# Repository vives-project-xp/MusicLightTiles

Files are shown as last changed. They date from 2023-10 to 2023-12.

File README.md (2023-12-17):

# MusicLightTiles

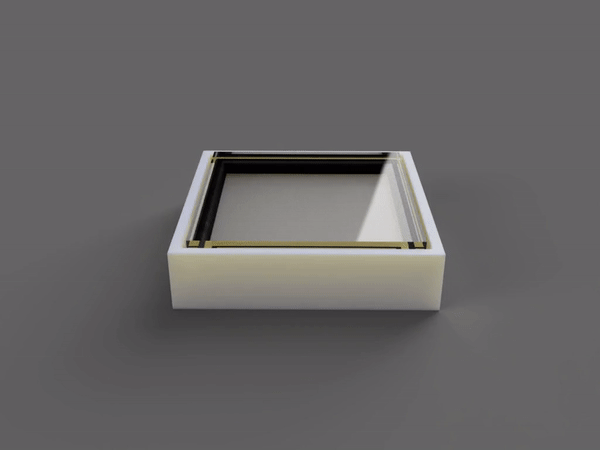
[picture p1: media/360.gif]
360° view


## About

Welcome to the MusicLightTiles project!  
This project was created as part of the Project Experience course at [VIVES University of Applied Sciences](https://www.vives.be/en).  
The goal of this project was to create a Proof of Concept interactive floor tile that can play music and light up when someone stands on it.
The tile also needed to work with [Project Master](https://github.com/vives-project-xp/ProjectMaster).  

## The team

- [Rob Cocquyt](https://github.com/Robbedoes24)
- [Ruben Belligh](https://github.com/RubenBelligh)
- [Luca De Clerck](https://github.com/LucaClrk)
- [Alberiek Depreytere](https://github.com/AlberiekDepreytere)

## Features

- Small form factor
- Can work standalone or as a set
- Hardcoded and wireless modes
- Add your own music
- Individualy addressable RGB leds
- Tested for 85kg of weight
- Can detect people starting from 5kg
- Works with [Project Master](https://github.com/vives-project-xp/ProjectMaster)

## How it works

Each tile has an ESP32 microcontroller that controls the lights and music and detects when someone stands on the tile.  
The tile reacts differently depending on the mode it is in, more info about this in the [Modes](#modes) section.  

### Person detection

To detect when someone stands on the tile, the ESP32 uses a simple circuit with 2 conductive strips.  
When someone stands on the tile, the conductive strips touch each other and close the circuit.  
To make sure the circuit is normally open, the tile uses seal strip to keep the plate (where people stand on) and the base (where the circuit is) separated.  
This way, the circuit is only closed when someone stands on the tile, because the seal strip is compressed.  
When the person later leaves the tile, the seal strip will decompress and push the plate back up, opening the circuit again.  

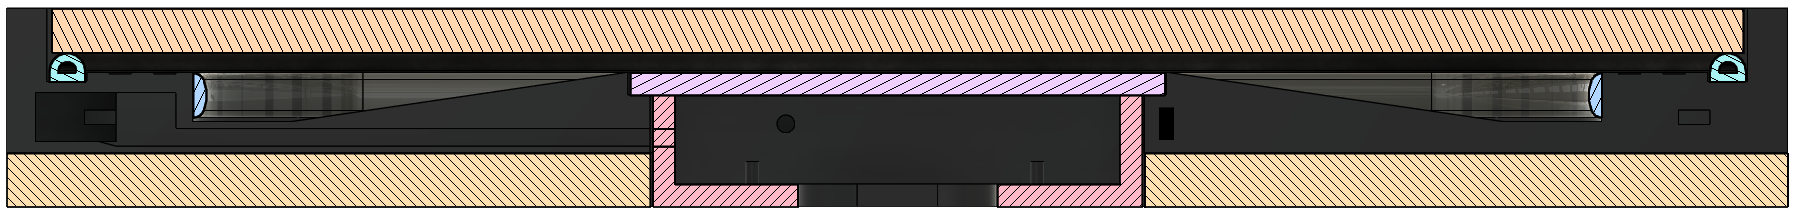
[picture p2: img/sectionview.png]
Section View


### Audio

For the audio, we use a DFPlayer Mini.
This is a small mp3 player that can be controlled with a serial connection.  
The ESP32 sends commands to the DFPlayer Mini to play, pause, stop, change volume, etc.  
The player has a micro SD card slot where you can put your own music.  
This player also has a built-in amplifier, so you can connect a speaker directly to it (3W speaker recommended).  

### Lights

For the lights, we use a WS2814 LED strip.  
This is a 24v LED strip with individually addressable RGB led sections.  
Each section has 6 leds and is about 10cm long.  

## Modes

The tiles can work in 2 modes:

- Hardcoded mode (Demo mode)
- Wireless mode (MQTT mode)

### Demo mode

In this mode, every tile will work on its own.  
When someone stands on a tile, the lights will turn on and music will start playing.  
When the person leaves the tile, the lights will turn red  and music will stop.  

### MQTT mode

In this mode, the tiles basically function as a sensor and actuator.  
When the state of a tile changes (like when someone stands on it), it will send a message to the MQTT broker.  
When a tile receives a command from the MQTT broker, it will execute the command and change its state accordingly.  

With the help of the server, you can control multiple tiles with the same command.  
This makes it possible to create a set of tiles that work together and can be controlled from a single point.  

## Project state

This project is currently in a working state.  
The tiles can be used in both modes and can be controlled with the [Project Master](https://github.com/vives-project-xp/ProjectMaster).  
There is an api available to control the tiles with websocket messages.
We started on a web interface to control the tiles, but this is not finished yet.

## Documentation

If you want to build your own tile(s) or build further on this project, you can find all aditional information in the [Wiki](https://github.com/vives-project-xp/MusicLightTiles/wiki).    

## Future improvements

- Finish the web interface.
- Replace the led strip with a 5v one, so the leds can be controlled individually.
- Replace the DFPlayer Mini with custom circuitry, so there won't be any delay when playing music.
- Add effects to the control server.
- Make the tiles cheaper to produce (so they can be used in schools, etc.).

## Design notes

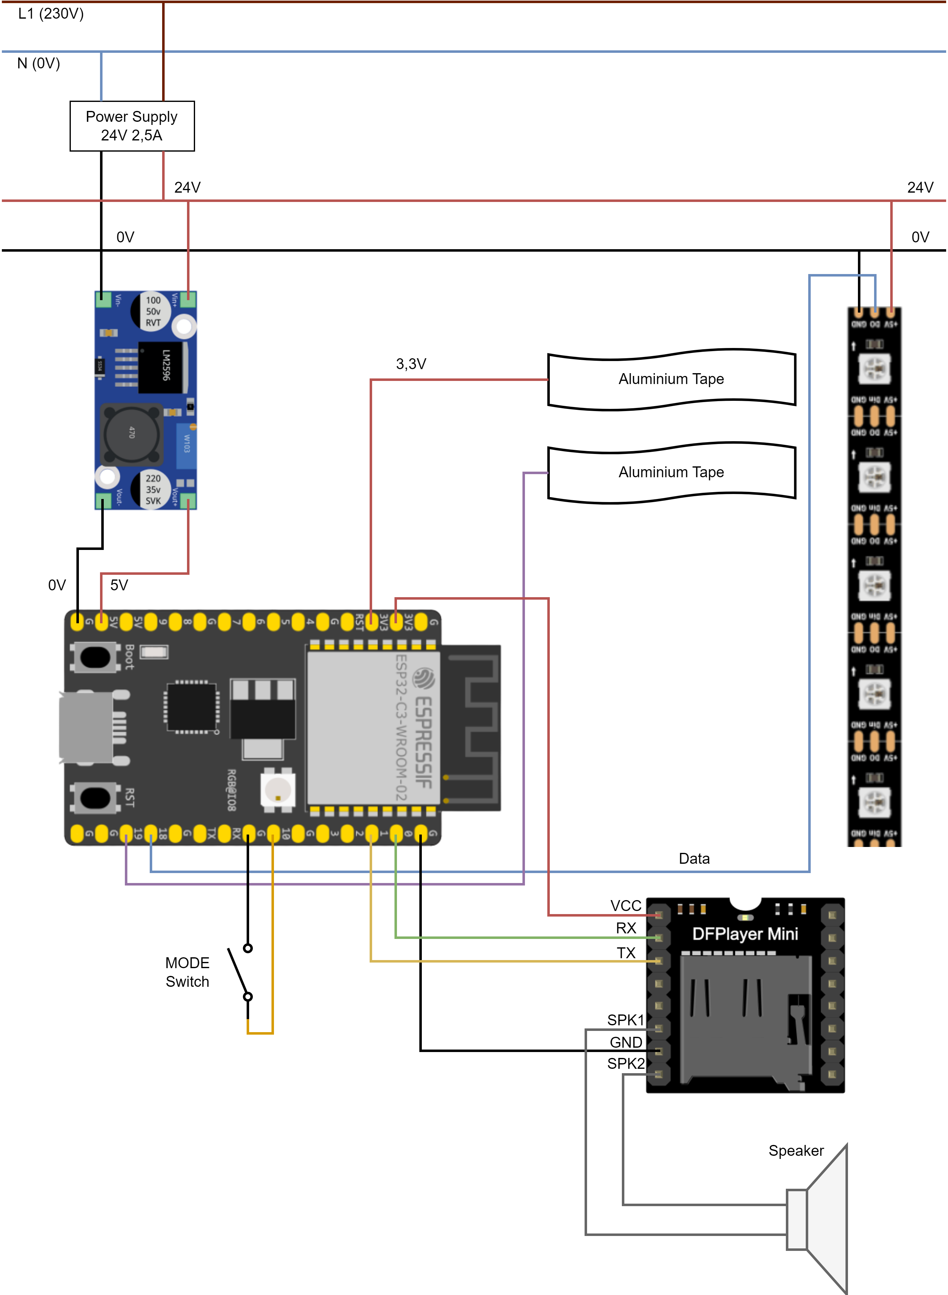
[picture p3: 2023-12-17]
img/electrical_diagram_v1.png

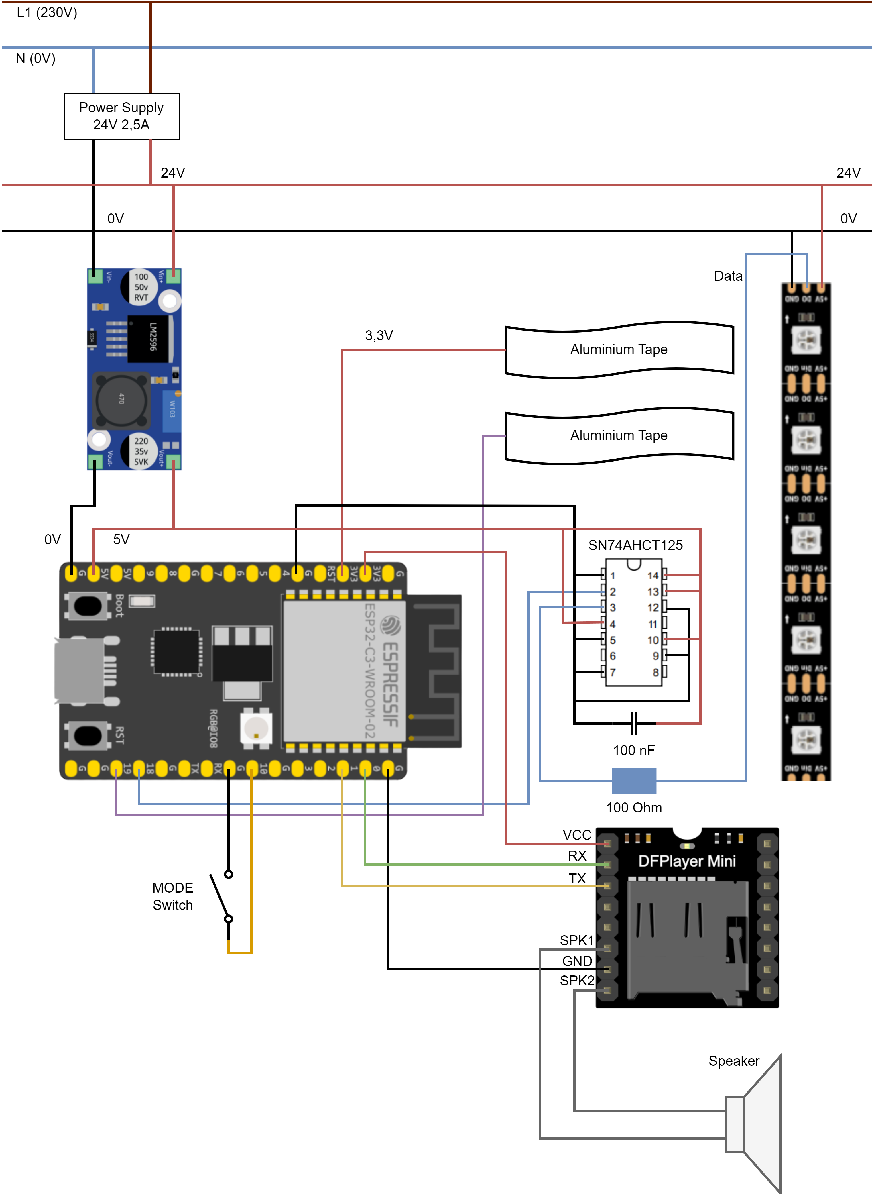
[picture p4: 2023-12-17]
img/electrical_diagram_v2.png

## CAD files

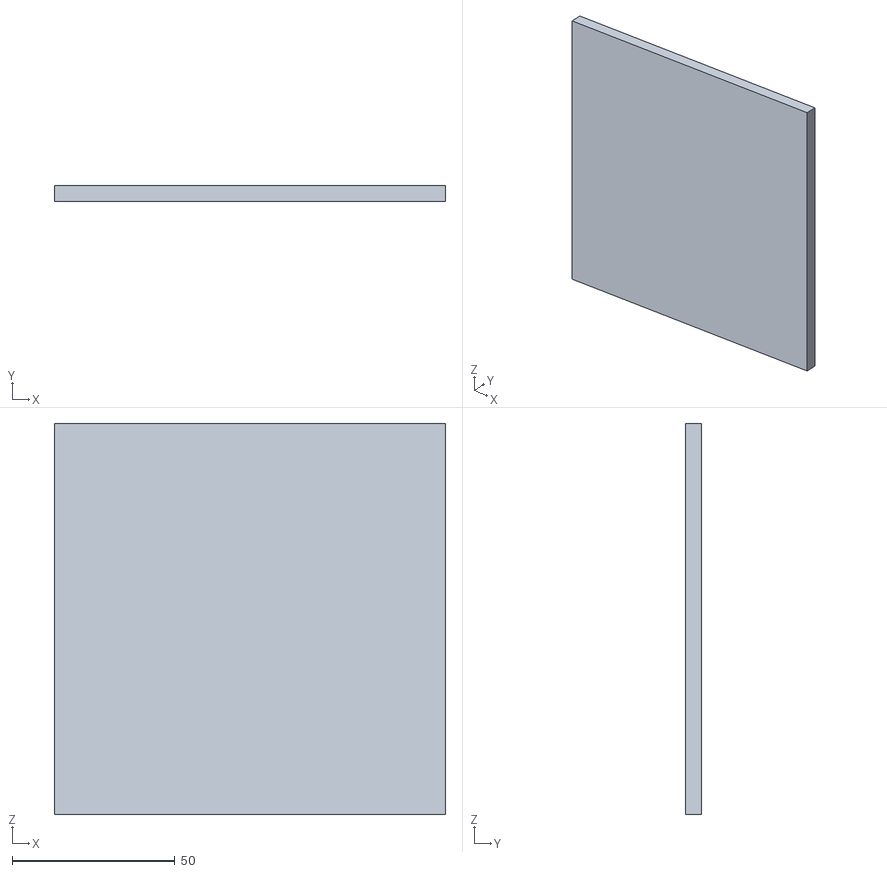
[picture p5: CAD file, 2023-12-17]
hardware/v2/stl/Electronics-box-lid.stl
120.0 x 5.00 x 120.0

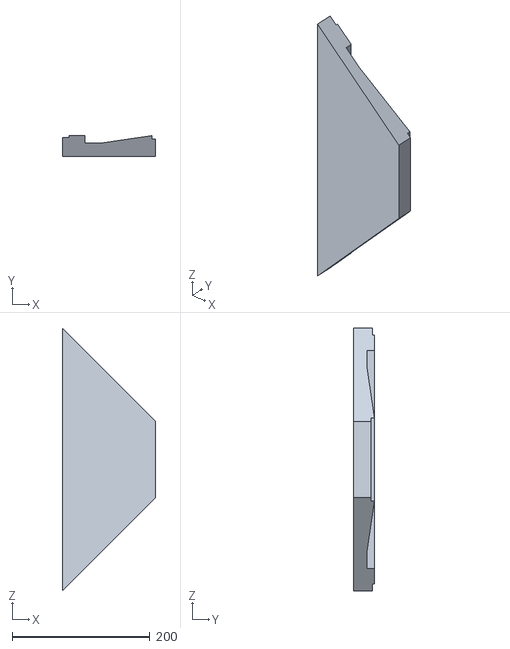
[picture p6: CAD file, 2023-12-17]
hardware/v2/stl/Base-type1.stl
135.5 x 30.0 x 382.0

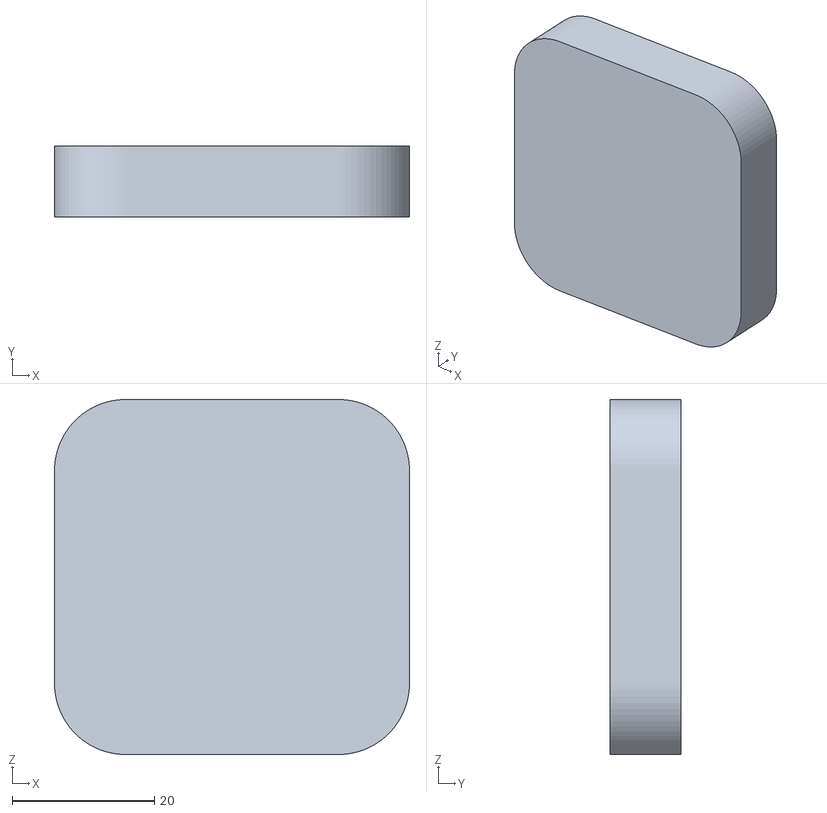
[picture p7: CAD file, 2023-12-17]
hardware/v2/stl/Feet.stl
50.0 x 10.0 x 50.0

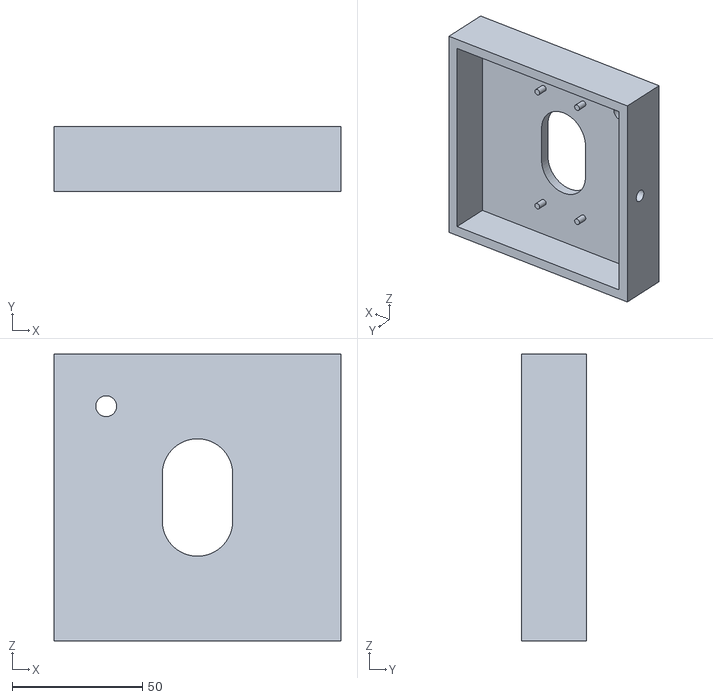
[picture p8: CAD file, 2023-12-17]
hardware/v2/stl/Electronics-box.stl
110.0 x 25.0 x 110.0

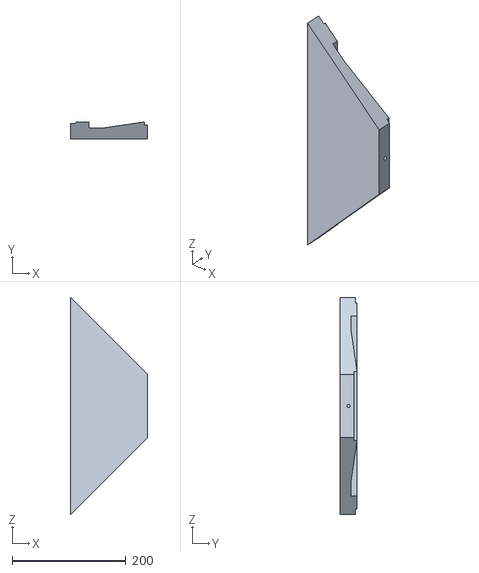
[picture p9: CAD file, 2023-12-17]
hardware/v2/stl/Base-type2.stl
135.5 x 30.0 x 382.0

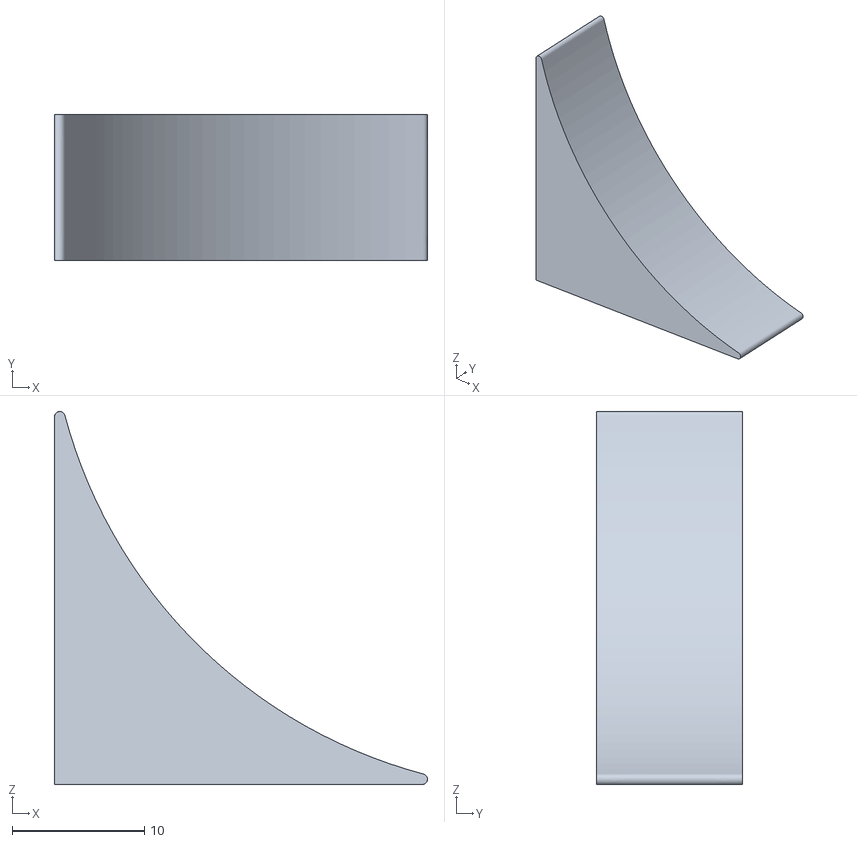
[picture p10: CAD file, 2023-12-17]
hardware/v2/stl/Corner.stl
28.2 x 11.0 x 28.2

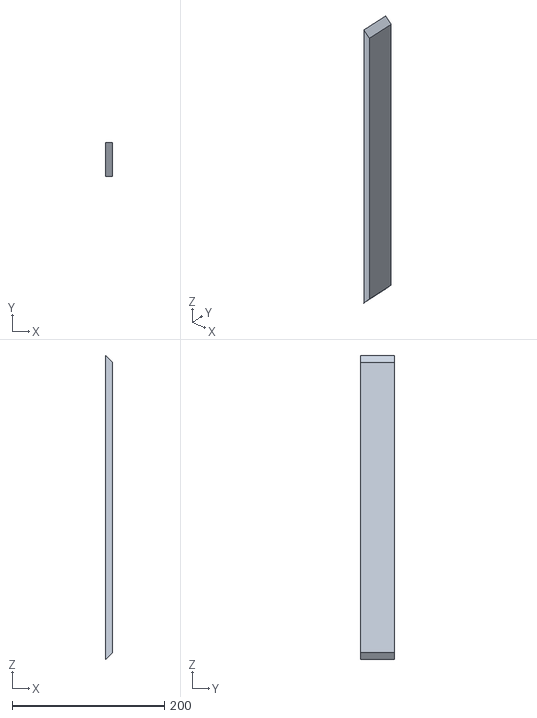
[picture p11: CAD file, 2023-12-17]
hardware/v2/stl/Side.stl
9.00 x 45.0 x 400.0

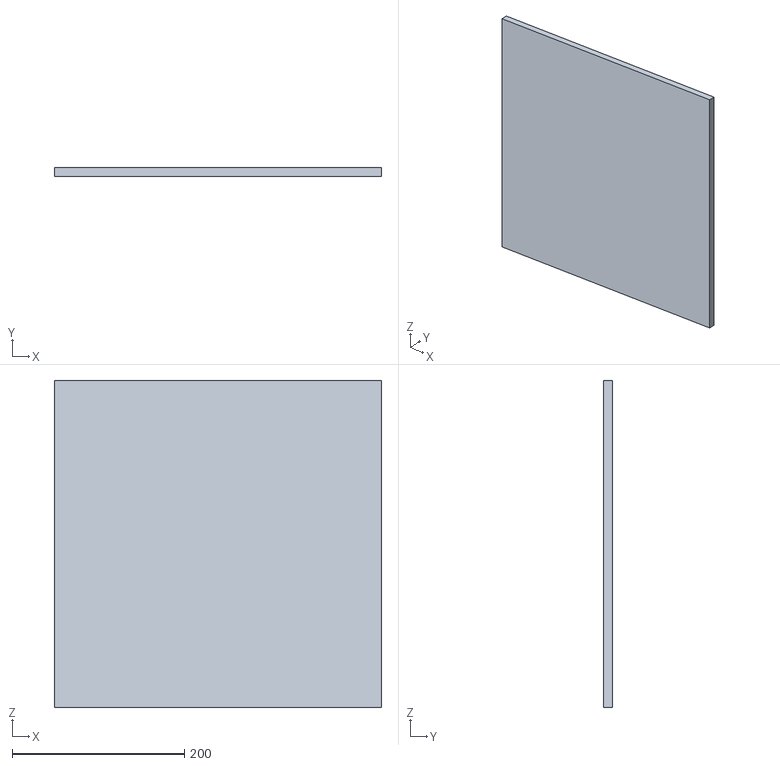
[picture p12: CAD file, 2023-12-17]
hardware/v2/stl/Plate.stl
380.0 x 10.0 x 380.0

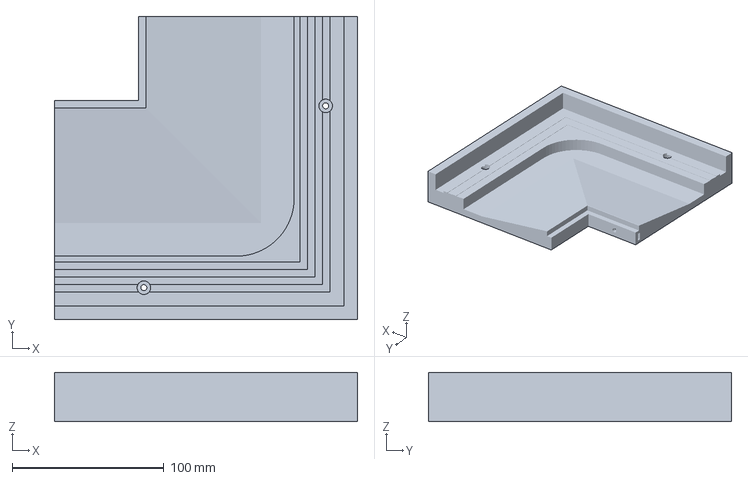
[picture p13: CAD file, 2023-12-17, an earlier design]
hardware/v1.5/cura/BaseCorner_Type1.3mf
200.0 x 200.0 x 32.5 mm

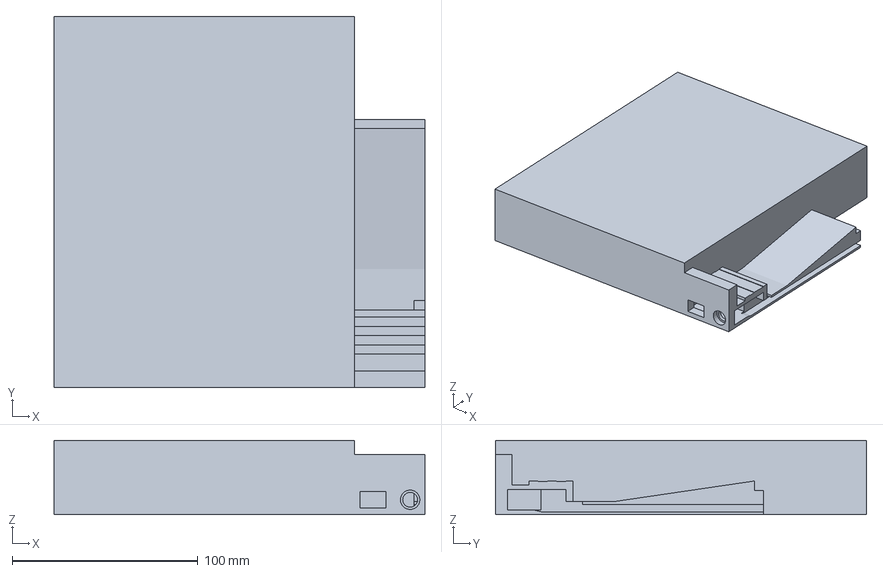
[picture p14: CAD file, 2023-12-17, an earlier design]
hardware/v1/cura/BaseCorner_Type2.3mf
200.0 x 200.0 x 40.0 mm

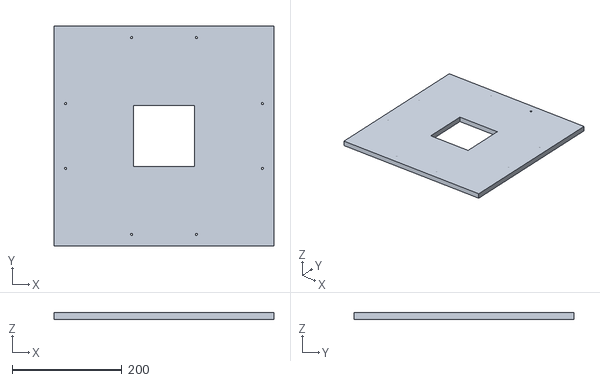
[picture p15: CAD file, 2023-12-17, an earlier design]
hardware/v1/stl/BasePlate.stl
400.0 x 400.0 x 12.0

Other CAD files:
hardware/v1.5/stl/BaseCorner_Type2.stl
hardware/v1/stl/InsertCover.stl
hardware/v1.5/stl/BaseCorner_Type1.stl
hardware/v1/stl/BaseCorner_Type2.stl
hardware/v1.5/stl/Insert.stl
hardware/v1.5/3d/Speaker.f3d
hardware/v1.5/3d/Tile.f3z
hardware/v1.5/stl/InsertCover.stl
hardware/v1.5/stl/Plate.stl
hardware/v1/3d/Speaker.f3d
hardware/v1/3d/Tile.f3z
hardware/v1/stl/BaseCorner_Type1.stl
hardware/v1/stl/Insert.stl
hardware/v1/stl/Plate.stl
hardware/v2/3d/Speaker.f3d
hardware/v2/3d/TileV2.f3z

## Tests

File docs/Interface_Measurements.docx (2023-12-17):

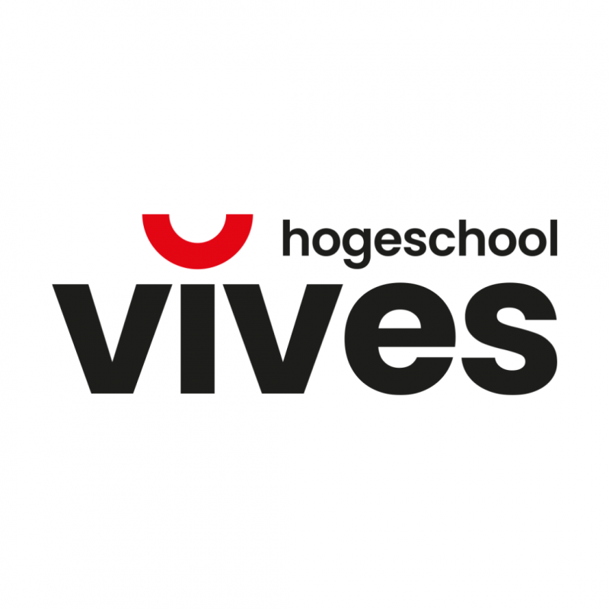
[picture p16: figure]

Opleiding: | Bachelor in de elektronica-ICT | Academiejaar: | 2023 – 2024
Klas: | / | Naam: | Alberiek Depreytere
Groepsleden: | Ruben Belligh Rob Cocquyt Luca De Clerck | Datum uitvoering: | Week van 11 December

o | Verslag - opdracht
o | Voorbereiding
Opleidingsonderdeel: | Project Experience
Titel opdracht: | Elektrische schema’s

# Inleiding

In dit verslag zijn alle versies van onze tegel terug te vinden. De werking en ook onze definitieve uitwerking.

# 1. VERSIE 1

Dit is het eerste prototype

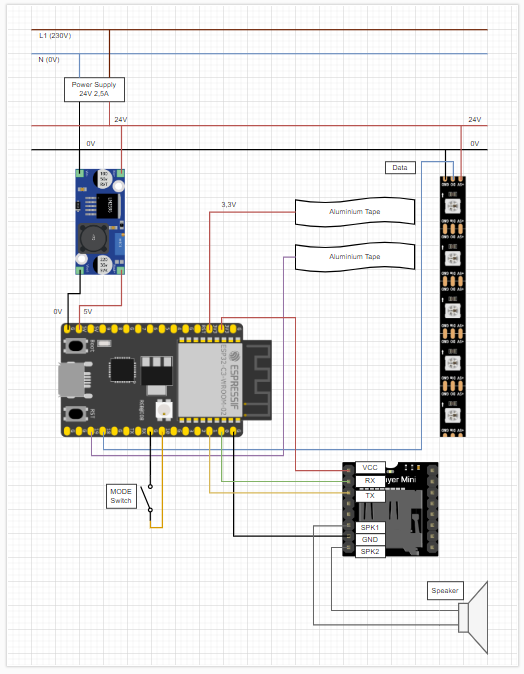
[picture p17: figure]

# 2. VERSIE 1.5

Dit is het tweede prototype.

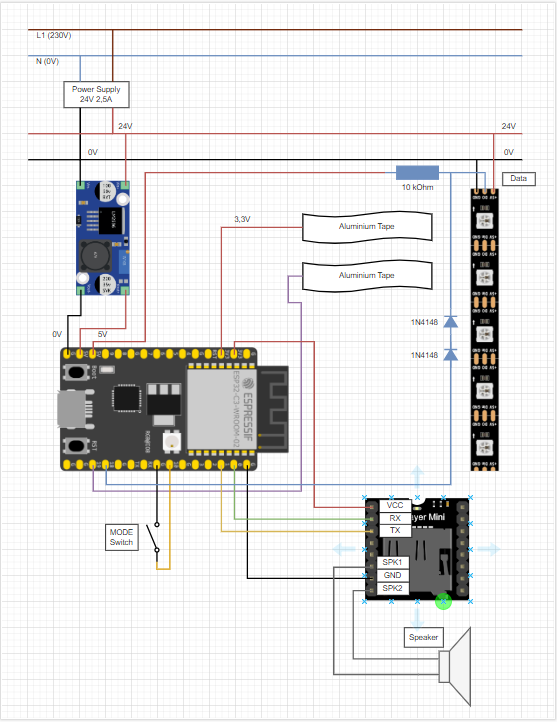
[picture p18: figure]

Componenten en werking.

We gebruiken een 24 Volt adapter voeding met barreljack (kortweg 24V voeding). In de schakeling wordt deze door de LM2596S DC-DC Step down Module (kortweg stepdown) verlaagd naar ±5V.

De ESP32-C3-DevKit-02 (kortweg ESP), waar onze code is op ingeladen, wordt gebruikt voor het aansturen van de Volledige schakeling.

Bij de MP3-TF-16P (kortweg MP3) in de schakeling zit er een 3W 8 Ohm speaker die wordt aangestuurd door de mp3 module (en die op zijn beurt door de ESP). Deze werkt via de RX en TX lijn samen met de esp. Voor seriële communicatie.

De WS2814 ledstrip (kortweg leds) wordt ook aangestuurd ook door de ESP.

Bij dit prototype helpt een 1n4148 diode ervoor dat de 5 Volt niet in aanraking komt met de 3V3 van onze ESP. Samen met een 10 kOhm weerstand.

We hebben ook een kleine 2pins modeswitch aangebracht voor wanneer onze ESP met het netwerk verbonden moet zijn of standalone kan werken. De Mp3 speler leest de data af van de SD kaart die met vooraf aangevulde liedjes werkt.

De aluminium plakband zorgt ervoor dat bij connectie (Wanneer er iemand op de tegel staat.) De Esp een signaal binnen zal krijgen en in werking zal kunnen treden.

Hieronder zijn de waarden in de schakeling genoteerd zoals te zien is wijken deze soms af van de theroretische waarden. In dit geval is het echter niet te veel om zorgen over te maken.

| Spanning
Leds | 24,263V
Leds full brightness | 24,212V | (Fel wit licht)
Detectie | 3,287V
DC/in | 24,258V | (Powersupply)
DC/out | 4,896V | (Uit de
GND en 5V ESP | 4,895V
3V3 | 3,295V | (ESP32-C3-DevKitC-02)
Switchon | 0,0025mV
Switchoff | 3,846V
VCC mp3 | 3,295V

Hieronder staan enkele voorbeelden van de seriële communicatie die plaatsvind tussen de MP3 speler en de ESP.

Bij onderstaande signalen zie je duidelijk dat we eerst een startbyte krijgen met daarna de data en de selectie van de registers (selecteren op de SD kaart welk liedje er afgespeeld moet worden, daarna komt er een duidelijk stop signaal) bij de scoop konden we dit niet naar Ruwe data vertalen (1- en 0-en).

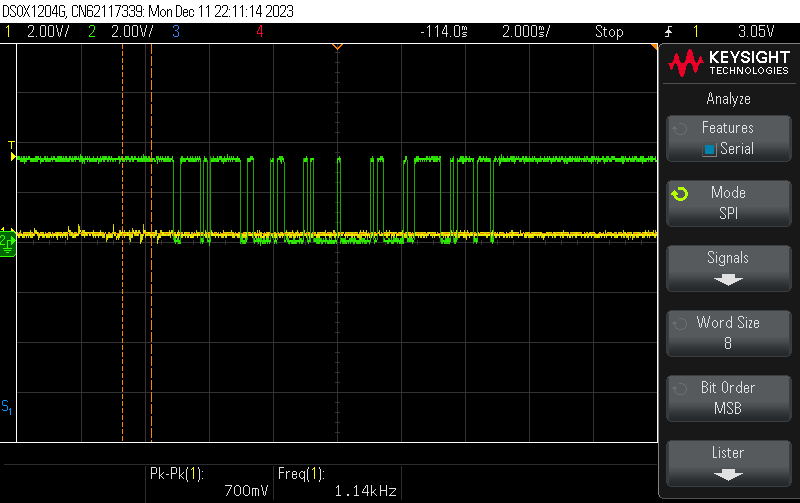
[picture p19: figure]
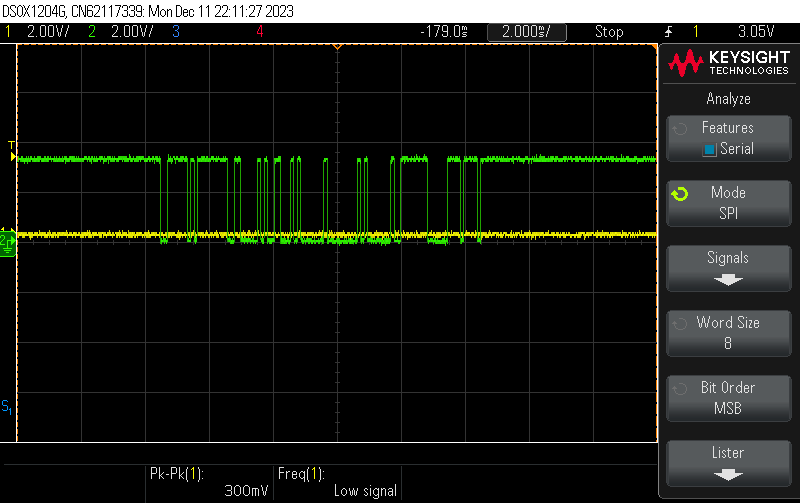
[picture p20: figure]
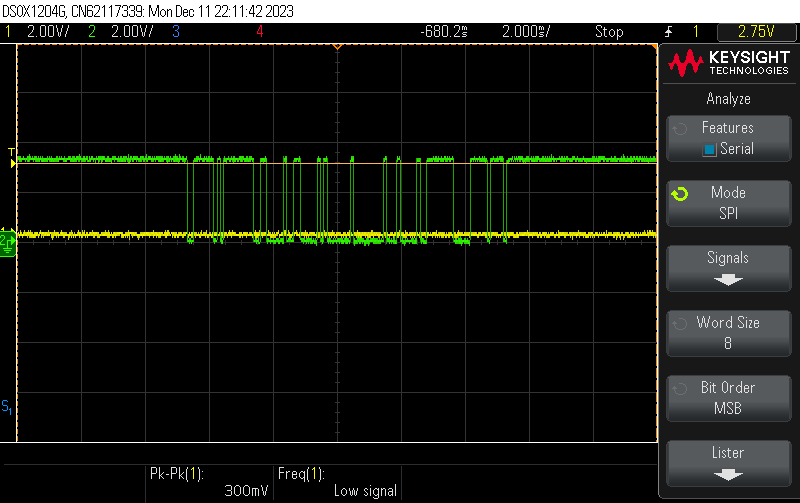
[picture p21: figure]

# 3. VERSIE 2

Dit is onze definitieve versie In tegenstelling tot het vorige prototype gebruiken we hier een levelshifter.

Ons datasignaal zal stabieler worden verhoogd (geschift naar een hoger lever).

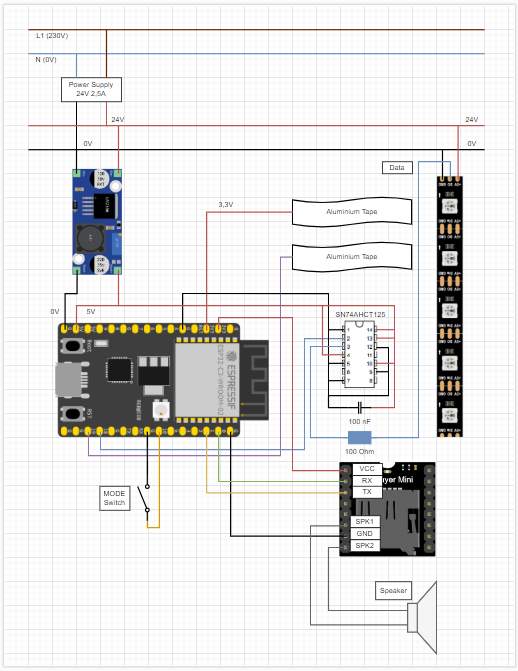
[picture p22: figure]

KATHOLIEKE HOGESCHOOL VIVES – STUDIEGEBIED IW&T – CAMPUS BRUGGE, KORTRIJK en OOSTENDE 1

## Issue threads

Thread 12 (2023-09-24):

Program detection section

Robbedoes24, 2023-09-24:
Create a program to detect the presence of something/someone using the controller and the detection methode.

Robbedoes24, 2023-10-08:
Added initial PlatformIO project to detect branch

RubenBelligh, 2023-10-09:
I've watched videos on how to program with arduino. The reason for this is that I have never programmed with Arduino.

RubenBelligh, 2023-10-09:
I programmed the detection. The button allows pin 16 to connect to the ground.

RubenBelligh, 2023-10-16:
I have made a flowchart of my program. In that chart you can see easily what it does.

Robbedoes24, 2023-10-19:
Merged feature detect into develop

Closed 2023-10-19.

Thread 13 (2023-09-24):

Program lighting section

Robbedoes24, 2023-09-24:
Create a program to adjust the lighting using the controller and the lighting solution.

Robbedoes24, 2023-10-08:
Added initial PlatformIO project to light branch

LucaClrk, 2023-10-09:
# First code for ledstrip
Today I finished the first code for the ledstrip. I used the Adafruit Neopixel library as it was the best for our ledstrip, the WS2814 RGBW. First I tested what this ledstrip could do. After testing we learned that this ledstrip is divided in segments of 6 leds. So this means we can't program each led individually but we can program each segment as we want. For 1 tile we needed 16 segments as this was around 1.6 meters. The length we needed for 1 tile. We know that the ledstrip will eventually be controlled by a signal sent by MQTT. I will receive an array that will control what segments light up and which color they will have. So for testing I made a 2D array "arrayPixel[16][4]. This basically says it contains 16 segments and 4 colors. It's an RGBW ledstrip so we have red, blue, green and a white led for additional brightness. Then I iterate over this array with a for loop. The for loop will go over all the segments and will determine the colors. I will make this clear with the following screenshots.

### The array
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
This is the array I used for my testing. In the next phase this array will be sent through MQTT.

### The for loop
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
Here you see the for loop iterating over the "NUMPIXELS". "NUMPIXELS" is equal to 16 and is declared above the setup. It says the amount of segments used. Next you can see all the colours [0, 1, 2, 3]. Later defined as red, white, green and blue. At last I say that the leds will work on a brightness of 50%.

LucaClrk, 2023-10-09:
# Backup Code

As mentioned in my previous comment, the array will be sent through MQTT. However, in case MQTT is not fast enough and the lights start flickering, I have created a backup code with hard-coded lighting patterns. I am using a button as the detection method for this backup code. When the button is activated, the lighting will turn on and remain in that state. When I deactivate the button by pressing it again, the lights will all turn red. Currently, the lights are static, but in the future, I would like to add effects to the lighting. This backup code serves as a fail-safe.

### Button Activated
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

In this section, I code how the button is activated. I achieve this by comparing the current state of the button with the state before that current state. This is how I determine if the button is active or not, and it will remain in that state. The colors used here are the same as in the previous program.

### Button Deactivated
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

This section consists of a simple `else` structure that uses the array to turn all the LEDs red. There is a small delay to eliminate any residual effects from the button. In the future, this delay may be removed.

Robbedoes24, 2023-10-19:
Merged feature light into develop

Closed 2023-10-19.

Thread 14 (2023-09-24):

Program control and communication section

Robbedoes24, 2023-09-24:
Create a program to let the controller communicate with the [Project master](https://github.com/vives-project-xp/ProjectMaster) using MQTT.

Robbedoes24, 2023-10-08:
Added initial PlatformIO project to mqtt branch

Robbedoes24, 2023-10-09:
Started with programming the mqtt section:
- Switched to different board (using az-delivery esp32 while our order is being shipped)
- Added a library that was used in the example (use and necessity are being looked at)
- Added library to project to setup mqtt and wifi communications
- Added basic mqtt functionality (subscribe to a topic and send data to another)
- Added secret header file and edited .gitignore (so we don't leak environment variables like passwords, etc.)
- Made the esp send an time alive (seconds) and cpu cycle to the mqtt broker (to test functionality and speed)

The following thing to do is test the subscriptionportion of the code.

Robbedoes24, 2023-10-15:
Added WIP documentation of how this project uses mqtt.
This includes all topics, there respected payloads and some info about each parameter of the payloads.
This document should be moved to the wiki when mqtt is implemented.

Robbedoes24, 2023-10-15:
Updated main.cpp:
- Added callback handling for subscribed mqtt topics (payload itself still needs to be processed)
- Removed publish of a cycle counter

Library changes:
- Removed now unused SRAM library (mostly because it didn't work, and isn't needed)
- Added file extension to lib/readme file

General changes:
- Added .gitignore (to ignore drawio temp files)
- Added basic mqtt flowchart
- Removed space from secret copy.h as this is unwanted in filenames

Robbedoes24, 2023-10-19:
Reviewed the code and everything seems to work as intended.

Closed 2023-10-19.

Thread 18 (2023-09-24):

Create full scale 3d model

Robbedoes24, 2023-09-24:
Create a full scale 3d model for the product with room for all the components and wiring.

RubenBelligh, 2023-11-06:
I made an email for the printing of our 3d model. The reason is that our project takes a lot of time to print and there are more printers in the making lab.

Robbedoes24, 2023-11-06:
3d models are finnished (for now).

Closed 2023-11-06.

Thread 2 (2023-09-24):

Choose detection methode

Robbedoes24, 2023-09-24:
Decide which method to use for detecting the presence of a person on the tile.

Robbedoes24, 2023-09-24:
**Currently discussed methods:**

- Motion sensor
- Presuremat
- Loadcell
- FSR (force-sensing resistor)
- Swith/contact (with movement or flexing of pannel)
- Strain gauge

Closed 2023-09-25.

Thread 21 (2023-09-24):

Build product

Robbedoes24, 2023-09-24:
Build one product for full scale testing and debugging.

Robbedoes24, 2023-11-10:
Printed the tile insert (1x) to house most of the electrical components.

Robbedoes24, 2023-11-19:
- wooden bottom is sawn and drilled
- polycarbonate plate is sawn

Robbedoes24, 2023-12-03:
tile has been build and seems to work, further testing required.

Closed 2023-12-03.

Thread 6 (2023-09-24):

Decide on requirements and attributes for prototype and product

Robbedoes24, 2023-09-24:
Decide which requirements and attributes the prototype and product should have to be successful.

Robbedoes24, 2023-09-24:
### **Proposal**

**Attributes**

_Size_
- prototype: 100 x 100 mm (height not important)
- product: 400 x 400 mm (height as low as possible)

**Requirements**

_Max weight (person)_
- prototype: not important
- product: 100 kg (more if possible)

_Trigger range (weight of person)_
- prototype: !to be decided!
- product: 5 to 100 kg

Robbedoes24, 2023-09-25:
Proposal has been approved

Closed 2023-09-25.

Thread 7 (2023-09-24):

Create and order BOM list

Robbedoes24, 2023-09-24:
- [x] List all needed components.
- [x] Add type and place to order components.
- [x] Discuss with project leader.
- [x] Submit to order.

Robbedoes24, 2023-09-25:
Needed components:

| Item | Model | Price | Link |
| :----: | :------: | :----: | :----: |
| Powerbrick 5v 30w | . | . | [text](url) |
| ESP-32 with wifi | . | . | [text](url) |
| USB-C breakout board | . | . | [text](url) |
| USB-C cable 2m | . | . | [text](url) |
| Ledstrip (individually addressable leds)  | . | . | [text](url) |
| Tochtstrip (type D) | . | . | [text](url) |
| Aluminium Tape | . | . | [text](url) |
| AMP 5v | . | . | [text](url) |
| Speaker 4w | . | . | [text](url) |
| Sd-card module (esp) | . | . | [text](url) |
| Sd-card min 4gb | . | . | [text](url) |

Robbedoes24, 2023-10-02:
Added components to order sheet

Closed 2023-10-02.

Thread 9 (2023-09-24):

Create electrical diagrams for individual sections and prototype

Robbedoes24, 2023-09-24:
Create electrical diagrams for the following sections:

- [x] Audio
- [x] Lighting
- [x] Detection
- [x] Control and communication

And a combined diagram for the prototype.

LucaClrk, 2023-10-02:
Schema van ledstrip circuit gemaakt. We maken gebruik van een ESP32, WS2814 en een supply. Er kan ook nog een capaciteit gebruikt worden tussen de 24V en de GND maar dit is net noodzakelijk.

RubenBelligh, 2023-10-02:
I made an electrical diagram of the detection system. This is connected to our microcontroller the ESP32.

Robbedoes24, 2023-10-08:
I combined the electrical diagrams into 1 file, made a combined diagram with all sections and cleaned up the individual diagrams with wire colores and images of the components.

Closed 2023-10-08.

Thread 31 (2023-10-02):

Create flowcharts and documentation

Robbedoes24, 2023-10-02:

RubenBelligh, 2023-10-02:
I made a flowchart. This gives us an idea of how the components are connected to each other.

Robbedoes24, 2023-10-08:
Will be replaced with more specific issues for each flowchart/documentation

Closed 2023-10-08.

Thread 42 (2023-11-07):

Create test script

Robbedoes24, 2023-11-07:
## Create a test script to test if a tile is working correctly.

### Files:
The files can be placed in a `testing` folder in the root directory of the repo.
- .env script for secrets (mqqt- host, port, username, password)
- copy.env (copy of .env, because .env should not be pushed to github)
- main.py (the script, using python)
- ... more if necessary

### Program Flow (from a user perspective)
1. Ask user for topic (ask again if incorrect)
2. Display all possible tiles to test (example: 1 - ABE64FHF616, 2 - 846ZFFG45 etc... )
3. Ask user for tile selection (one of the previous tiles, or multiple [extra])
4. Loop the following:
    - Run each possible command (change every pixel color, play audio, change volume, reboot, etc)
    - Ask user for visual confirmation (for every command run, no by default)
6. List everything that has been tested, the confirmation and a `pass` or `fail`
7. Ask the user if they want to test another device (yes or no) and run again if necessary

### Notes:
- The program flow above is just what the user should experience, so don't forget about thing like connecting to mqtt where no user input is required
- If a command is send and an invalid responds is received, the tile still fails (even if there is visual confirmation)

RubenBelligh, 2023-11-08:
I created a test script for the project. It tests the tiles by sending them various commands and then receives a visual confirmation.

RubenBelligh, 2023-11-18:
I continued working on the script because it was not yet completely in order.

RubenBelligh, 2023-11-19:
Debuggen of the code

LucaClrk, 2023-11-20:
# First code
I have attempted to make code to be able to test the tiles. I have used python to make a connection with MQTT and send commands and read the tiles.

## Code
### MQTT Settings
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
Here I make sure I have the MQTT settings right so I can make a connection with it. For now I am only subscribed to TILE1. I still have to figure out how to connect to all active tiles.

### Using topics
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
Here I subscribe to the topics I need to test the tile. I will test the audio, light and system. These are the subtopics of the command subtopic. I also subscribed to the presence subtopic. This will read if the tile is active or not.
Next I have programmed functions for the audio, light and system.
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
Here I send the commands to MQTT to test the tiles.

## Solution
This is my code untill now. I have not gotten further as things are starting to get more complicated.

Robbedoes24, 2023-12-15:
Test script is done.

Closed 2023-12-15.

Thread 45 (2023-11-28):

3D design v2

Robbedoes24, 2023-11-28:
Adjust 3d design for easier manufacturing

Robbedoes24, 2023-12-11:
Finished v2 of the tile design, this version is made to be 'mass-produced'.
- The corners and electronics-box should be 3d printed.
- The base (type 1 and 2) should be milled (from wood).
- The sides and electronics-box-lid can simply be cut from some wooden planks.
- The plate should be poly carbonate plate.
- The material of the feet can be chosen, but should not compress much.

Closed 2023-12-11.

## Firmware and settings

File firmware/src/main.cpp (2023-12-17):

// Import necessary libraries
#include <Arduino.h>
#include <WiFi.h>
#include <PubSubClient.h>
#include <ArduinoJson.h>
#include <Adafruit_NeoPixel.h>
#include <DFRobotDFPlayerMini.h>

// Import secret.h (contains the projects secrets and configuration)
#include "secret.h"

// Define mode enum (mode switch)
enum Mode {
  DEMO,
  MQTT
};

// Define audio action enum (audio_state + audio_mode)
enum AudioAction {
  IDLE_PLAY = 1,
  IDLE_PAUSE = 2,
  IDLE_RESUME = 3,
  IDLE_STOP = 4,
  PLAY_PLAY = 11,
  PLAY_PAUSE = 12,
  PLAY_RESUME = 13,
  PLAY_STOP = 14,
  PAUSE_PLAY = 21,
  PAUSE_PAUSE = 22,
  PAUSE_RESUME = 23,
  PAUSE_STOP = 24
};

// Define pixel struct (led strip pixel)
struct Pixel {
  int red;
  int green;
  int blue;
  int white;
};

// Define pin constants
#define MODE_SWITCH_PIN 10 // pin for mode switch
#define PRESENCE_PIN 19    // pin for presence detection
#define LEDSTRIP_PIN 18    // pin for led strip
#define RX_PIN 1           // pin rx, should be connected to tx of dfplayer
#define TX_PIN 0           // pin tx, should be connected to rx of dfplayer

// Define constants
const int uptimeInterval = 1000; // interval in milliseconds to update uptime

// Define device specific constants
const int amount_of_pixels = 12; // amount of pixels in the led strip
const char* firmware_version = "1.0.0";
const char* hardware_version = "1.5.0";
const String sounds[] = {
  "A cat meowing",
  "A dog barking",
  "A duck quacking",
  "A frog croaking",
  "A horse neighing",
  "A pig grunt",
  "A rooster crowing",
  "A chicken clucking",
  "A sheep baaing",
  "A wolf howling",
  "Minecraft villager",
  "Minecraft creeper hissing",
  "Minecraft explosion",
  "Mario jump",
  "Mario coin",
  "Mario death",
  "Among Us role reveal",
  "Fortnite death",
  "Roblox oof",
  "CS:GO bomb planted",
  "CS:GO bomb defused",
  "GTA San Andreas - Here we go again",
  "GTA V wasted",
  "GTA V phone ring",
  "Bruh sound effect",
  "Emotional damage",
  "Sad violin",
  "Windows XP error",
  "Windows XP shutdown",
  "Windows XP startup",
  "Piano C note",
  "Piano C# note",
  "Piano D note",
  "Piano D# note",
  "Piano E note",
  "Piano F note",
  "Piano F# note",
  "Piano G note",
  "Piano G# note",
  "Piano A note",
  "Piano A# note",
  "Piano B note",
  "Applause",
  "Kids cheering",
  "Crickets",
  "Wheel spin",
  "Wrong answer",
  "Right answer",
  "Intermission",
  "The Office - That's what she said",
  "The Office - No, God! No, God, please no! No! No! Nooooooo!",
  "Obi-Wan Kenobi - Hello there"
}; // All sounds that can be played (available on the sd card of the dfplayer)
const int amount_of_sounds = sizeof(sounds) / sizeof(sounds[0]);

// Define global objects
Mode mode = DEMO; // default to demo mode
WiFiClient wifiClient;
PubSubClient client(wifiClient);
Adafruit_NeoPixel ledstrip = Adafruit_NeoPixel(amount_of_pixels, LEDSTRIP_PIN, NEO_WRGB + NEO_KHZ800);
HardwareSerial hs(1);
DFRobotDFPlayerMini dfplayer;

// Define global variables
String device_name = "tile";
String stateTopic = "state";
String commandTopic = "command";

int cycle = 0;

bool reboot = false;
bool ping = true;
bool previous_ping = ping;
unsigned long uptime = 0;
unsigned long lastUptime = 0;

bool presence = false;
bool previous_presence = false;

int audio_mode = 4; // 1 = play, 2 = pause, 3 = resume, 4 = stop
int previous_audio_mode = 4;
int audio_state = 0; // 0 = idle, 1 = playing, 2 = paused
bool audio_loop = false;
bool previous_audio_loop = false;
String sound = sounds[0]; // Take first sound in sounds array as default
String previous_sound = sound;
int volume = 0; // 0-30
int previous_volume = 0;

int brightness = 1; // 0-255 (0 = off, 255 = full brightness)
int previous_brightness = 1;
Pixel pixels[amount_of_pixels] = {Pixel{0, 0, 0, 0}};
Pixel previous_pixels[amount_of_pixels] = {Pixel{0, 0, 0, 0}};

// Function prototypes
void demo_setup();
void demo_loop();
void mqtt_setup();
void mqtt_loop();
void callback(char* topic, byte* payload, unsigned int length);
void connectToWifi();
void disconnectFromWifi();
void connectToMqtt();
void disconnectFromMqtt();
bool updateSystem();
bool updateUptime();
String getSystemState();
bool updateAudio();
bool audioPlayerStateChanged();
String getAudioState();
bool updateLights();
String getLightState();
bool updatePresence();
String getPresenceState();

// Setup function
void setup() {
  // Set serial monitor baud rate for debugging purposes
  Serial.begin(115200);

  // Initialize the mode switch pin as an input with internal pullup resistor (pressed = LOW, not pressed = HIGH)
  pinMode(MODE_SWITCH_PIN, INPUT_PULLUP);

  // Set mode from button state
  if (digitalRead(MODE_SWITCH_PIN) == HIGH) {
    mode = DEMO;
  } else {
    mode = MQTT;
  }

  // General setup
  Serial.println("Running general setup...");
  // Setup presence detection pin as input with internal pulldown resistor (pressed = HIGH, not pressed = LOW)
  pinMode(PRESENCE_PIN, INPUT_PULLDOWN);
  // Setup led strip (set leds to off)
  ledstrip.begin();
  ledstrip.setBrightness(1);
  ledstrip.show();
  // Setup audio
  hs.begin(9600, SERIAL_8N1, RX_PIN, TX_PIN);
  dfplayer.begin(hs); // Use hardware serial to communicate with DFPlayer Mini
  dfplayer.setTimeOut(500); // Set serial communication time out 500ms
  dfplayer.volume(volume); // Set volume off
  dfplayer.EQ(DFPLAYER_EQ_NORMAL);  // Set EQ to normal

  // Initialise program depending on mode
  if (mode == DEMO) {
    // Run demo setup
    demo_setup();
  } else if (mode == MQTT) {
    // Run mqtt setup
    mqtt_setup();
  } else {
    // Something went wrong, print error and do nothing
    Serial.println("Unknown mode, doing nothing...");
  }
}

// Loop function
void loop() {
  // Run loop depending on mode
  if (mode == DEMO) {
    // Run demo loop
    demo_loop();
  } else if (mode == MQTT) {
    // Run mqtt loop
    mqtt_loop();
  } else {
    // Something went wrong, print error and do nothing
    Serial.println("Unknown mode, doing nothing...");
    delay(1000); // Wait some time to prevent spamming the serial monitor with errors
  }
  // Update cycle counter
  cycle++;
}

// Demo setup function (setup for demo mode)
void demo_setup() {
  // Run demo setup
  Serial.println("Running demo setup...");
  // Audio seettings for demo mode (these don't change while running demo mode)
  // Set sound
  sound = "Mario jump";
  // Set volume
  volume = 30; // 15 = 50% volume
  // Set audio loop
  audio_loop = true;
  // Set brightness to 150
  brightness = 150;
}

// Demo loop function (loop for demo mode)
void demo_loop() {
  // If presence has changed
  if (updatePresence()) {
    // If presence is detected
    if (presence) {
      // Fill all pixels with the color green
      for (int i = 0; i < amount_of_pixels; i++) {
        pixels[i].red = 0;
        pixels[i].green = 255;
        pixels[i].blue = 0;
        pixels[i].white = 0;
      }
      // Set audio to play
      audio_mode = 1;
    } else {
      // Fill all pixels with the color green
      for (int i = 0; i < amount_of_pixels; i++) {
        pixels[i].red = 255;
        pixels[i].green = 0;
        pixels[i].blue = 0;
        pixels[i].white = 0;
      }
      // Set audio to stop
      audio_mode = 4;
    }
    // Update lights
    updateLights();
    // Update audio
    updateAudio();
  }
}

// MQTT setup function (setup for MQTT mode)
void mqtt_setup() {
  // Run MQTT setup
  Serial.println("Running MQTT setup...");

  // Set device name to mac address of ESP32
  String mac = WiFi.macAddress();
  mac.replace(":", "");
  device_name = mac;

  // Set state and command topics
  stateTopic = String(root_topic) + "/" + String(device_name) + "/self/state";
  commandTopic = String(root_topic) + "/" + String(device_name) + "/self/command";

  // Set wifi hostname to device name
  WiFi.setHostname(device_name.c_str());

  // Connect to Wi-Fi
  connectToWifi();

  // Update MQTT settings
  client.setBufferSize(2048); // Set MQTT packet buffer size
  client.setServer(mqtt_server, mqtt_port);
  client.setCallback(callback);

  // Connect to MQTT broker
  connectToMqtt();
}

// MQTT loop function (loop for MQTT mode)
void mqtt_loop() {
  // If not connected to Wi-Fi, try to connect
  if (WiFi.status() != WL_CONNECTED) {
    // Disconnect from Wi-Fi
    disconnectFromWifi();
    // Connect to Wi-Fi
    connectToWifi();
  }

  // If not connected to MQTT broker, try to connect
  if (!client.connected()) {
    // Disconnect from MQTT broker
    disconnectFromMqtt();
    // Connect to MQTT broker
    connectToMqtt();
  }

  // Keep the MQTT connection alive look for incoming messages
  client.loop();

  // If reboot is true, reboot
  if (reboot) {
    Serial.println("Rebooting...");
    // Disconnect from MQTT broker
    disconnectFromMqtt();
    // Disconnect from Wi-Fi
    disconnectFromWifi();
    // Reboot
    ESP.restart();
  }

  // Update system
  if (updateSystem()) {
    client.publish((stateTopic + "/system").c_str(), getSystemState().c_str());
  }

  // Update audio
  if (updateAudio() || audioPlayerStateChanged()) {
    client.publish((stateTopic + "/audio").c_str(), getAudioState().c_str());
  }

  // Update lights
  if (updateLights()) {
    client.publish((stateTopic + "/light").c_str(), getLightState().c_str());
  }

  // Update presence
  if (updatePresence()) {
    client.publish((stateTopic + "/presence").c_str(), getPresenceState().c_str());
  }
}

// MQTT callback function
void callback(char* topic, byte* payload, unsigned int length) {
  // Print the topic and payload for debugging purposes
  Serial.println("Message arrived in topic: " + String(topic));
  //Serial.println("Message: " + String((char*)payload));

  // Parse commands from payload for each subtopic
  if (String(topic) == commandTopic + "/system") 
  {
    StaticJsonDocument<32> doc;
    DeserializationError error = deserializeJson(doc, payload, length);
    if (error) {
      Serial.print("deserializeJson() failed: ");
      Serial.println(error.c_str());
      return;
    }

    reboot = doc["reboot"];
    ping = doc["ping"];
  } 
  else if (String(topic) == commandTopic + "/audio") 
  {
    StaticJsonDocument<64> doc;
    DeserializationError error = deserializeJson(doc, payload, length);
    if (error) {
      Serial.print("deserializeJson() failed: ");
      Serial.println(error.c_str());
      return;
    }

    audio_mode = doc["mode"];
    audio_loop = doc["loop"];
    sound = (const char*)doc["sound"];
    volume = ((int)doc["volume"] / 100.0) * 30;  // Convert volume from 0-100 to 0-30
  } 
  else if (String(topic) == commandTopic + "/light") 
  {
    StaticJsonDocument<1024> doc;
    DeserializationError error = deserializeJson(doc, payload, length);
    if (error) {
      Serial.print("deserializeJson() failed: ");
      Serial.println(error.c_str());
      return;
    }

    brightness = doc["brightness"];

    JsonArray light_pixels = doc["pixels"];
    for (int i = 0; i < amount_of_pixels; i++) {
      // Try to get pixel from json array, if it doesn't exist, leave current values
      try {
        // Set pixel values
        JsonObject pixel = light_pixels[i];
        pixels[i].red = pixel["r"];
        pixels[i].green = pixel["g"];
        pixels[i].blue = pixel["b"];
        pixels[i].white = pixel["w"];
      } catch (...) {
        // Do nothing
      }
    }
  }
  else {
    Serial.println("Unknown topic, doing nothing...");
    Serial.println("commandTopic: " + String(commandTopic));
  }
}

// Connect to wifi function
void connectToWifi() {
  // Connect to Wi-Fi
  WiFi.begin(ssid, password);
  while (WiFi.status() != WL_CONNECTED) {
    delay(1000);
    Serial.println("Connecting to WiFi as " + device_name + "...");
  }
  Serial.println("Connected to WiFi as " + device_name);
}

// Disconnect from wifi function
void disconnectFromWifi() {
  // Disconnect from Wi-Fi
  WiFi.disconnect();
  while (WiFi.status() == WL_CONNECTED) {
    delay(1000);
    Serial.println("Disconnecting from WiFi as " + device_name + "...");
  }
  Serial.println("Disconnected from WiFi as " + device_name);
}

// Connect to MQTT broker function
void connectToMqtt() {
  // Replace mqtt user with device name if mqtt user is NULL
  if (mqtt_user == NULL) {
    mqtt_user = device_name.c_str();
  }
  // Connect to MQTT broker
  while (!client.connected()) {
    if (client.connect(device_name.c_str(), mqtt_user, mqtt_password, (String(root_topic) + "/" + String(device_name) + "/self").c_str(), 1, true, String("OFFLINE").c_str())) {
      Serial.println("Connected to MQTT broker as " + String(device_name));
      // Publish online message
      client.publish((String(root_topic) + "/" + String(device_name) + "/self").c_str(), String("ONLINE").c_str(), true);
      // Publish initial state
      client.publish((stateTopic + "/system").c_str(), getSystemState().c_str());
      client.publish((stateTopic + "/audio").c_str(), getAudioState().c_str());
      client.publish((stateTopic + "/light").c_str(), getLightState().c_str());
      client.publish((stateTopic + "/presence").c_str(), getPresenceState().c_str());
      // Subscribe to command subtopic
      client.subscribe((commandTopic + "/#").c_str());
      Serial.println("Connected to MQTT broker as " + String(device_name));
    } else {
      Serial.println("Failed to connect to MQTT broker, retrying in 5 seconds...");
      delay(5000);
    }
  }
}

// Disconnect from MQTT broker function
void disconnectFromMqtt() {
  // Disconnect from MQTT broker
  if (client.connected()) {
    // Publish offline message
    client.publish((String(root_topic) + "/" + String(device_name) + "/self").c_str(), String("OFFLINE").c_str(), true);
    // Disconnect from MQTT broker
    client.disconnect();
    while (client.connected()) {
      delay(1000);
      Serial.println("Disconnecting from MQTT broker as " + String(device_name) + "...");
    }
    Serial.println("Disconnected from MQTT broker as " + String(device_name));
  }
}

// Update system function
bool updateSystem() {
  if (ping != previous_ping) {
    // Ping has changed
    updateUptime();
    // Update previous ping
    previous_ping = ping;
    // State has changed, return true
    return true;
  } else if (ping) {
    return updateUptime();
  } else {
    updateUptime();
    // State hasn't changed, return false
    return false;
  }
}

// Update uptime function
bool updateUptime() {
  // Get current millis
  unsigned long currentMillis = millis();
  // If current millis - last uptime is greater than uptime interval
  if (currentMillis - lastUptime >= uptimeInterval) {
    // Update uptime
    uptime++;
    Serial.println("Updating uptime...");
    // Update last uptime
    lastUptime = currentMillis;
    // State has changed, return true
    return true;
  } else {
    // State hasn't changed, return false
    return false;
  }
}

// Get system state function (returns system state as JSON)
String getSystemState() {
  StaticJsonDocument<2048> doc;

  doc["firmware"] = firmware_version;
  doc["hardware"] = hardware_version;
  doc["ping"] = ping;
  doc["uptime"] = uptime;

  JsonArray system_sounds = doc.createNestedArray("sounds");
  for (int i = 0; i < amount_of_sounds; i++) {
    system_sounds.add(sounds[i]);
  }

  String output;
  serializeJson(doc, output);
  return output;
}

// Update audio function
bool updateAudio() {
  if (audio_mode != previous_audio_mode || sound != previous_sound || volume != previous_volume || audio_loop != previous_audio_loop) {

    Serial.println("Updating audio...");

    // Print current state for debugging purposes
    if (dfplayer.available()) {
      Serial.println("Player is available");
      Serial.println("Current state: " + String(audio_state));
    } else {
      Serial.println("Player is not available");
      Serial.println("Current state: " + String(audio_state));
    }

    // Create audio action from audio state and audio mode
    AudioAction audioAction = AudioAction((String(audio_state) + String(audio_mode)).toInt());
    Serial.println("Audio action: " + String(audioAction));

    // Check current audio state
    switch (audioAction){
      case IDLE_PLAY: case PLAY_PLAY: case PAUSE_PLAY:
        /* Play sound + Set volume + Set loop */
        Serial.println("Playing sound...");
        // Set volume
        dfplayer.volume(volume);
        // Set loop
        if (audio_loop) {
          dfplayer.enableLoop();
        } else {
          dfplayer.disableLoop();
        }
        // Play sound
        for (int i = 0; i < amount_of_sounds; i++) {
          if (sound == sounds[i]) {
            dfplayer.play(i + 1);
            break;
          }
        }
        // Set audio state to playing
        audio_state = 1;
        break;
      
      case IDLE_PAUSE: case IDLE_RESUME: case IDLE_STOP: case PAUSE_PAUSE:
        /* Set volume + Set loop */
        Serial.println("Setting volume and loop...");
        // Set volume
        dfplayer.volume(volume);
        // Set loop
        if (audio_loop) {
          dfplayer.enableLoop();
        } else {
          dfplayer.disableLoop();
        }
        break;

      case PLAY_RESUME:
        /* Pause sound + Set volume + Set loop + Resume sound */
        Serial.println("Setting volume and loop...");
        // Pause sound
        dfplayer.pause();
        // Set volume
        dfplayer.volume(volume);
        // Set loop
        if (audio_loop) {
          dfplayer.enableLoop();
        } else {
          dfplayer.disableLoop();
        }
        // Resume sound
        dfplayer.start();
        break;

      case PLAY_PAUSE:
        /* Pause sound + Set volume + Set loop */
        Serial.println("Pausing sound...");
        // Pause sound
        dfplayer.pause();
        // Set volume
        dfplayer.volume(volume);
        // Set loop
        if (audio_loop) {
          dfplayer.enableLoop();
        } else {
          dfplayer.disableLoop();
        }
        // Set audio state to paused
        audio_state = 2;
        break;

      case PLAY_STOP: case PAUSE_STOP:
        /* Stop sound + Set volume + Set loop */
        Serial.println("Stopping sound...");
        // Stop sound
        dfplayer.stop();
        // Set volume
        dfplayer.volume(volume);
        // Set loop
        if (audio_loop) {
          dfplayer.enableLoop();
        } else {
          dfplayer.disableLoop();
        }
        // Set audio state to idle
        audio_state = 0;
        break;

      case PAUSE_RESUME:
        /* Resume sound + Set volume + Set loop */
        Serial.println("Resuming sound...");
        // Set volume
        dfplayer.volume(volume);
        // Set loop
        if (audio_loop) {
          dfplayer.enableLoop();
        } else {
          dfplayer.disableLoop();
        }
        // Resume sound
        dfplayer.start();
        // Set audio state to playing
        audio_state = 1;
        break;
      
      default:
        // Unknown action, do nothing
        Serial.println("Unknown audio action, doing nothing...");
        break;
    }

    // Update previous values
    previous_audio_mode = audio_mode;
    previous_sound = sound;
    previous_volume = volume;
    previous_audio_loop = audio_loop;

    // State has changed, return true
    return true;
  } else {
    // Nothing has changed, return false
    return false;
  }
}

// Read player state function
bool audioPlayerStateChanged(){
  // Check if player is available
  if (dfplayer.available()) {
    // Check if player is done playing and audio is not looping
    if (dfplayer.readType() == DFPlayerPlayFinished && audio_loop == false) {
      Serial.println("Player is done playing");
      // Set audio state to idle
      audio_state = 0;
      // Set audio mode to stop, since the player is done playing
      audio_mode = 4;
      // State has changed, return true
      return true;
    } else {
      // No significant change, return false
      return false;
    }
  } else {
    // No significant change, return false
    return false;
  }
}

// Get audio state function (returns audio state as JSON)
String getAudioState() {
  StaticJsonDocument<96> doc;

  doc["state"] = audio_state;
  doc["looping"] = audio_loop;
  doc["sound"] = sound;
  doc["volume"] = (volume / 30.0) * 100;  // Convert volume from 0-30 to 0-100

  String output;
  serializeJson(doc, output);
  return output;
}

// Update lights function
bool updateLights() {
  // If brightness has changed or pixel colors have changed (value in pixels is different from previous value in pixels)
  if (brightness != previous_brightness || memcmp(pixels, previous_pixels, sizeof(pixels)) != 0) {

    // Wait for led strip to be ready
    while (!ledstrip.canShow()) {
      delay(0.0000125);
    }

    Serial.println("Updating lights...");
    // Set brightness to new value
    ledstrip.setBrightness(brightness);
    // Set pixels to new values
    for (int i = 0; i < amount_of_pixels; i++) {
      ledstrip.setPixelColor(i, ledstrip.Color(pixels[i].red, pixels[i].green, pixels[i].blue, pixels[i].white));
    }
    // Show changes
    ledstrip.show();

    // Update previous values
    previous_brightness = brightness;
    memcpy(previous_pixels, pixels, sizeof(pixels));
    // State has changed, return true
    return true;
  } else {
    // Nothing has changed, return false
    return false;
  }
}

// Get light state function (returns light state as JSON)
String getLightState() {
  StaticJsonDocument<1024> doc;

  doc["brightness"] = brightness;

  JsonArray light_pixels = doc.createNestedArray("pixels");
  for (int i = 0; i < amount_of_pixels; i++) {
    JsonObject pixel = light_pixels.createNestedObject();
    pixel["r"] = pixels[i].red;
    pixel["g"] = pixels[i].green;
    pixel["b"] = pixels[i].blue;
    pixel["w"] = pixels[i].white;
  }

  String output;
  serializeJson(doc, output);
  return output;
}
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

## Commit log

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2023-10-02 Readme updated esp32 price and link
    Updated to use mouser instead of az-delivery as requested.
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2023-10-15 #14 Added basic mqtt flowchart
    Added basic mqtt flowchart to blokschema file
2023-10-15 Added ArduinoJson library dependency
    Added ArduinoJson to PlatformIO project, for later use in sending and recieving json object over mqtt.
2023-10-15 #14 Added ArduinoJson library dependency
    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
2023-10-16 #14 Combined all individual libraries into one
    Updated the tile class to be the main class and implement the `Audio`, `Detect` and `Light` classes. The functionality of these classes is currently not existing, more work is required.
2023-10-16 #14 Edited device name definition
    Added a defined hardware and software version and declared the device name inside setup so it can be dynamically generated in the future.
2023-10-16 #14 Added topic filter before sending payload to tile class
    Added a safeguard so that only messages received from the command topic (which is the only one that we subscribed to) should be send to the tile class.
2023-10-16 #14 Updated mqtt.md
    Updated development documentation for mqtt with the latest move from one subtopic for each device feature on command an state topics to one payload for command and one payload for state.
2023-10-16 #14 Updated Tile class
    Added some functionality to the tile class, it is now able to send and receive json payloads over mqtt.
    Current behaviour:
    - Update uptime every second
    - Check for state changes every cycle
    - Update state every time a command is received or uptime is incremented
    - Reboot esp if reboot command is received
    main.cpp has been changed to work with the new tile class changes.
    [main.cpp]
2023-10-17 Updated and renamed flowchart
    Renamed to flowchart and added the following:
    - General program flowchart
    - Reformatted device connections
    - Reformatted mqtt flowchart
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2023-10-17 #14 Reworked main.cpp
    Reworked main.cpp to handle everything the tile class was currently doing. This has been done to increase ease of use.
    Still need some work to get back the same functionality as before.
    Also added a hardware switch that can decide the mode of the program "demo" or "mqtt".
    [main.cpp]
2023-10-18 #14 Updated callback function
    - Added topic validation (so we are sure the message comes from the right topic)
    - fixed build error when assigning sound the value of audio["sound"]. Needed to be const char* instead of char*
    [main.cpp]
2023-10-18 #14 Added MQTT user and last will
    - Added the possibility to use username/password to connect to mqtt broker.
    - Added last will and testament so the broker will send offline if device suddenly disconnects.
    [main.cpp]
2023-10-18 #14 Set device name as mac without :
    - Set device name to esp mac adress without ":"
    - Increased firmware version to 0.0.3
2023-10-18 #14 Added reconnect
    If connection to mqtt broker or wifi connection is lost, reconnect (using the mqtt setup function)
    [main.cpp]
2023-10-18 #14 Publish offline before reboot (mqtt)
    Added serial logging and publish OFFLINE message when device is restarted (in mqtt mode).
    [main.cpp]
2023-10-19 #14 Updated demo loop
    Updated demo loop to:
    - Play audio and power leds when presence is detected (on presence change)
    - Stop audio and power down leds when no presence is detected (on presence change)
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2023-10-19 #15 Update demo mode
    Updated demo mode to turn the ledstrip off when no presence is detected, instead of full brightness (0)
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2023-10-21 #15 Tried to add clean retry
    Tried to implement clean disconnect before attempting to reconnect to wifi and/or mqtt broker in case of a connection failure.
    [main.cpp]
2023-10-21 #15 Changed amount of pixels from define to const
    Changed amount_of_pixels from define to const since const provides type safety and enables the compiler to catch type-related errors.
    [main.cpp]
2023-10-21 #15 Changed audio implementation
    Changed the way audio is implemented to a single switch case. This is done so the code is easier to understand and more maintainable.
2023-10-21 Added excel doc used for calculating audio actions
    Added excel doc that was used for calculating audio actions by listing all possible inputs and there actions and simplifying it to the smallest possible form.
    [AudioActions.xlsx]
2023-10-22 #15 Replaced mqtt firmware by firmware
    Moved files from mqtt firmware to just firmware as mqtt doesn't only contain mqtt anymore.
    [main.cpp]
2023-10-23 #15 updated main.cpp
    - Use internal pullup resistors
    - Set ONLINE to retain
    - Some small changes
2023-10-26 #18 Added fusion360 project files
    Added fusion360 project files for the 3d design of the tile
    [Speaker.f3d, Tile.f3z]
2023-10-26 #18 Added stl files
    Added stl files for all major components.
    [BaseCorner_Type1.stl, BaseCorner_Type2.stl, BasePlate.stl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]
2023-10-26 #18 Renamed Lid to InsertCover
    [InsertCover.stl]
2023-10-26 Updated readme.md
    Added Extra 3d print details to the readme, like possible settings and needed parts and amounts.
2023-10-27 #15 Switched input pullup and pulldown
    Made mode switch pullup, so demo is default.
    Made detect button pulldown, so default is false.
2023-10-27 #15 Fixed brightness defaults
    It seems that 0 is off for the ledstrip, unlike what the documentation says. So i set the default value to 0. Also added this to demo mode. Commented color switch on no presence (demo mode) since ledstrip is off, so not usefull.
    [main.cpp]
2023-10-28 #26 Changed renders for better once
    Changed renders for better once.
    - Better camera position
    - Other background color
    - Other base color
    - On floor instead of floating (shadows)
    - 4k resolution instead of HD
2023-10-29 #20 Switched to other esp32 board
    Switched to esp32-c3-devkitm-1 board that will be used in the tile, instead of the az-delivery-devkit-v4 board that was used during development.
2023-10-30 #33 Fixed small error
    Switched to - instead of ' ' to prevent errors
2023-10-30 #20 Replaced all sections by pixels
    Changed all mentions of section to pixel.
    [main.cpp]
2023-10-30 #19 Modified electrical diagram
    Modified electrical diagram with new esp32 board and mode switch.
2023-10-31 #18 Added hole for ledstrip
    Added hole to route ledstrip cables to insert.
    [BaseCorner_Type2.stl, Tile.f3z]
2023-10-31 #36 Added create_command method to tile
    Added a create_command method to the tile class to create a command string for that tile, which fills in all blanks with the current tile state.
2023-10-31 Updated main.cpp
    Added fix for ping change not being sent.
    The esp now send another state when the ping state is switched.
    [main.cpp]
2023-10-31 #36 Updated main.py
    - Leds loop from 0 to 12 instead of reverse
    - Played with the timings
2023-10-31 #37 Reworked main.cpp
    Reworked main.cpp to follow the new way states and commands are send and received following the mqtt.md document. Also cleaned up some of the code:
    - New functions to connect and disconnect to/from wifi and mqtt
    - Reduced mqtt buffer size to 2048 (from 3072)
    - Reboot now disconnects from mqtt and wifi instead of just rebooting
    - Removed unused code in demo_loop
    [main.cpp]
2023-11-07 Updated Firmware
    Switched from custom sound (struct) array to a array of strings for the sounds.
2023-11-09 Convert to type for payload values (emulator)
    Try to convert the payload values to the right format. This is done so that invalid messages don't crash the thread (tile). Also added a '\n' to the prints in main.py so text isn't sticking to the back.
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2023-11-13 Updated stl files
    Updated the 3d model
    [BaseCorner_Type1.stl, BaseCorner_Type2.stl, BasePlate.stl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]
2023-11-13 Updated stl files
    new version of the tile. (3d files)
    [BaseCorner_Type1.stl, BaseCorner_Type2.stl, Tile.f3z]
2023-11-13 added cura projects for base corners
    [BaseCorner_Type1.3mf, BaseCorner_Type2.3mf]
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2023-11-20 Changed 3d model
    Changed 3d model to fix problems after first print
    [BaseCorner_Type1.stl, BaseCorner_Type2.stl, Tile.f3z]
2023-11-27 Testing the test code
    [AudioActions.xlsx]
2023-11-28 Updated main.cpp
    - changed demo setup and loop values
    - only check presence changes every 100 clock cycles to prevent bouncing
    [main.cpp]
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2023-12-05 Updated main.cpp
    - Lowered debounce
    - Wait for ledstrip to be ready
    - Updated demo loop
    - General code fixes
    [main.cpp]
2023-12-09 Replaced print with logging and removed dotenv lib
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2023-12-11 Moved v1 files to dedicated folder
    [BaseCorner_Type1.3mf, BaseCorner_Type1.stl, BaseCorner_Type2.3mf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]
2023-12-11 #45 Added files for 3d v2
    [Base-type1.stl, Base-type2.stl, Corner.stl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]
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2023-12-16 Cleaned up the hardware folder
    And moved electrical diagram to hardware folder.
    [BaseCorner_Type1.3mf, BaseCorner_Type1.stl, BaseCorner_Type2.3mf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]
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
